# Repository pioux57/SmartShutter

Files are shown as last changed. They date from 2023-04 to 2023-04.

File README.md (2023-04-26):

# SmartShutter Description
>FR Flag Pour la version française, [c'est par ici](READMEfr.md).
## What's this ?
SmartShutter is a DIY project allowing to drive a reflex digital camera, here it is a Nikon D600 but could be any device allowing a binary (on/off) input for shutter and focus, using a "standalone" device but also using a computer.
This project has been done from an original idea of Florent Pin on [storm chasers forum](https://forum.chasseurs-orages.com/viewtopic.php?t=6243), I have took this idea and adapted it to my needs in order to make a more evolved tool.

It provide different features like:
* Lightning detection (3 detection modes)
* Timelapse
* Simply remote control

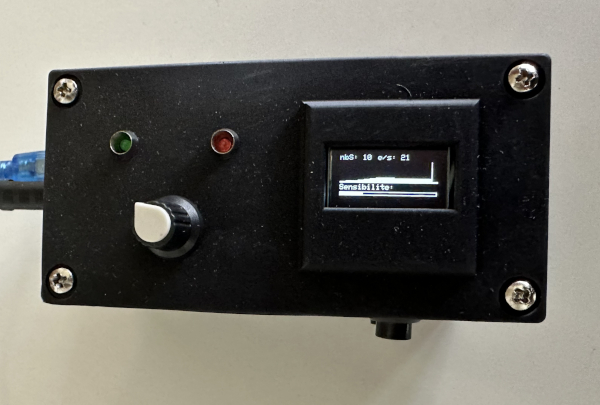
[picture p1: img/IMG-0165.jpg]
Front panel
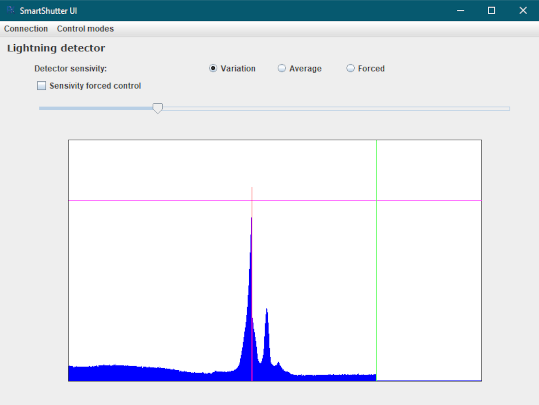
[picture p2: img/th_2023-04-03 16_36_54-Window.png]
UI
 
## And for which purpose ?
I designed it mainly to use my reflex camera to take pictures from stars, galaxys, planets, with my telescope. And additionaly to try to do some lightning pictures. Ability to trigger a picture without touching the telescope setup (no vibrations) and without quiting my computer, is convenient when we do astrophotography.

## User guide
### Main features
There are 3 main features available:
* __Lightning detection__: Triggers a shot from the camera when detect any flash in the direction of the photosensor. 3 detections modes are available:
  * _Variation_ : Will detect a quick change of the ambiant brightness, you can adjust the sensivity of the detection with the potentiometer (depicted by an horizontal line on the screen)
  * _Average_ : Will detect when the brightness exceed the average of the latest measures, you can adjust the sensivity of the detection with the potentiometer (depicted by an horizontal line on the screen)
  * _Forced_ : Will detect when the brightness exceed the threshold set with the potentiometer (depicted by an horizontal line on the screen)
* __Timelapse__: Will trigger a shot from the camera each times the elapsed time is reached. This delay is displayed on the screen in minutes and can be changed using the potentiometer
* __Direct shot__: Will trigger a shot every time you push the "SET" button

### Change feature
If you want to change the selected feature, push the "MODE" button. It will cycle the features like this: `Lightning detection > Timelapse > Direct Shot`.

Lightning detection Timelapse Direct Shot

### Change detection mode
This option is available only in __Lightning detection__, to change the detection mode, push the "SET" button. It will cycle the detection modes like this: `Variation > Average > Forced`.

Lightning detection Lightning detection Lightning detection
>`nbS` means "Number of Shots" - `e/s` means number of measure per second

### Power supply
User any of the standard way to power an Arduino. Through USB using a computer or a portable power bank, or by the Jack power input using a battery case or a live transformer.

# Software

## Arduino code

### The program itself
Code for programming the Arduino controller can be found under `src` folder. It is written in "real" C++ (I'm using PlatformIO under VSCode), but can be easily ported to Arduino IDE.
The program will require following libraries:
```
#include <Wire.h>
#include <Adafruit_GFX.h>
#include <Adafruit_SSD1306.h>
```
>Note that the big hexadecimal part at the beginning was to display my logo on the OLED screen at startup but I've disabled this part to save memory in the microcontroler.

This code can be adapted and transformed but be careful ! I am very close to overload the Arduino available memory, so if you add too much additional variable you may encounter some memory troubleshooting like glitches on the screen, freezing of the Arduino and so on.

### Settings adaptations
You will see at the begining of the code the following constants, they are there in order to adjust some values according to your wiring and components. I give you below the english translation of the comments who indicate what each constant talks about:
```
#define POTENTIOMETER_MAX   940         // Maximum analog value of the potentiometer (you have to measure that by testing it)
#define POTENTIOMETER_MIN   30          // Minimum analog value of the potentiometer (you have to measure that by testing it because it's never a real zero)
#define SENSIBILITY_MAX     100         // Maximum sensitivity wanted
#define SENSIBILITY_MIN     3           // Minimum sensitivity wanted
#define HISTORY_DEPTH       16          // Length of the stored measure array (default 16) !! Careful here, if you put a big value, you will be in memory trouble
#define VALUE_MAX           960         // Maximum analog value of the phototransistor (you have to measure that by testing it)
#define DEBOUNCE_TIME       10          // Button push debounce time
#define TIMELAPSE_GAP       10          // Default timelapse steps duration
#define TIMELAPSE_MAX       1440        // Maximum duration of the whole timelapse cycle
#define USB_LATENCY         10          // Millisecond delay to be used during serial communication with the computer and the UI
```

## Computer UI code
Code for the computer UI is written in groovy and can be executed using a local jdk or jre engine (java). Usually everyone have this installed in a standard Windows OS. The needed jar libraries are provided under `UI/lib` but you can use the latest ones by uncommenting and adapting the maven part in the UI launcher `SmartShutter.bat`.

The program can take 2 optional parameters in input (both can be used at the same time):
* `SmartShutter debug` : Will start the UI in DEBUG MODE
* `SmartShutter lang:en` : Will set the language to english (en) or french (fr). French is default.
>You can update the `.bat` launcher to force any of these parameters to avoid to type it every time.

1. At startup, the software will try to detect the device by itself so it will be better that the device is already connected to the computer before launching the software.
2. Go to "Connection" menu and choose "Connection to SmartShutter", the result of the autodetection will be displayed

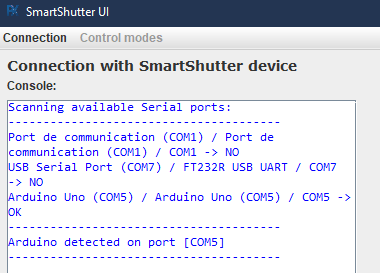
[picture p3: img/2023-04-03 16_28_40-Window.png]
   

3. Click on "Connection" to start the communication between the software and the device

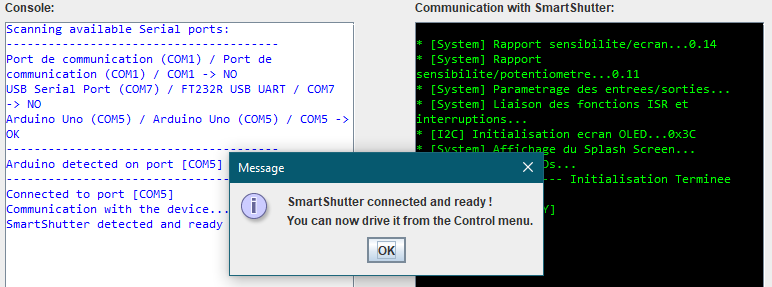
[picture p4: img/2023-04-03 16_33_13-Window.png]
   

Once this step done, you can use all the other features of the software to take control of the device from the computer.
# Hardware

## Skills
This project can be done without any specific skills other than tin soldering. 3D printing skills are optional as you can use the box you want to put the hardware in, or very limited skills as the 3D design is already done for you and available in this repository (stl files). Same for wiring as all the schematics are available in this repository too (fritzing sketch, png and diy files).

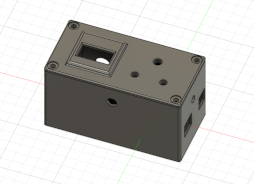
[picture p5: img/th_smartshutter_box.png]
3D Design in Fusion360
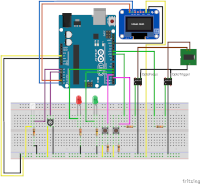
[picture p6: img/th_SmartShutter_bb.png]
Wiring in Fritzing
 

## Material
* 1x Arduino Uno
* 1x [OLED Screen I2C 128x64](https://amzn.eu/d/16eJRzV)
* 1x Red 3mm LED
* 1x Green 3mm LED
* 2x Optocoupler (4N35)
* 1x Potentiometer (0 to 10kOhms)
* 2x Push buttons
* 1x [Phototransistor (3DU5C)](https://amzn.eu/d/ha9QPGW)
* 1x Female Jack 2.5mm connector
* 2x 220 Ohms resistors
* 5x 10k Ohms resistors
* 1x [Prototyping card for soldering additional components](https://amzn.eu/d/ezlYbJF)

## Wiring
I provide 3 types of schematics for wiring to help you building this project.
### Fritzing sketch
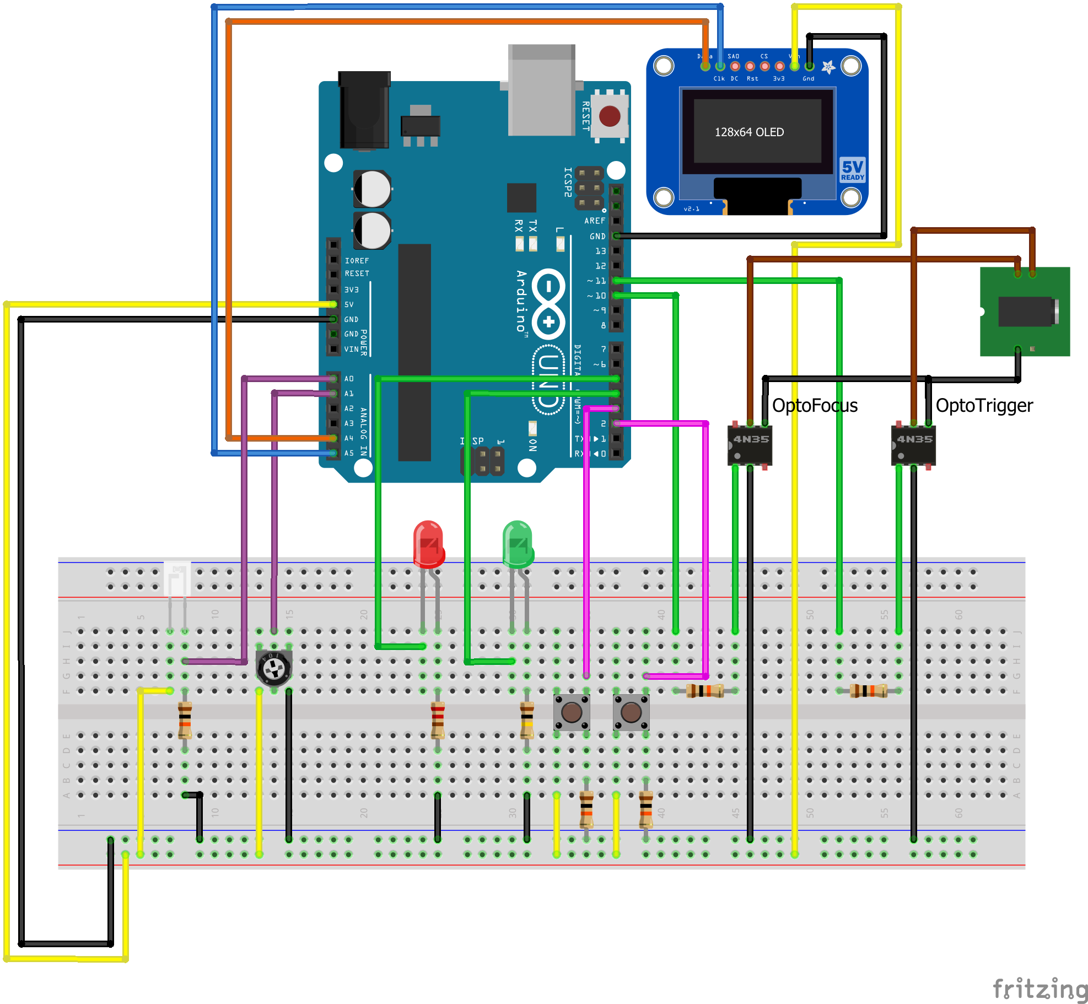
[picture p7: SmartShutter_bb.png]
fzz file

### DIYLC sketch for prototyping card
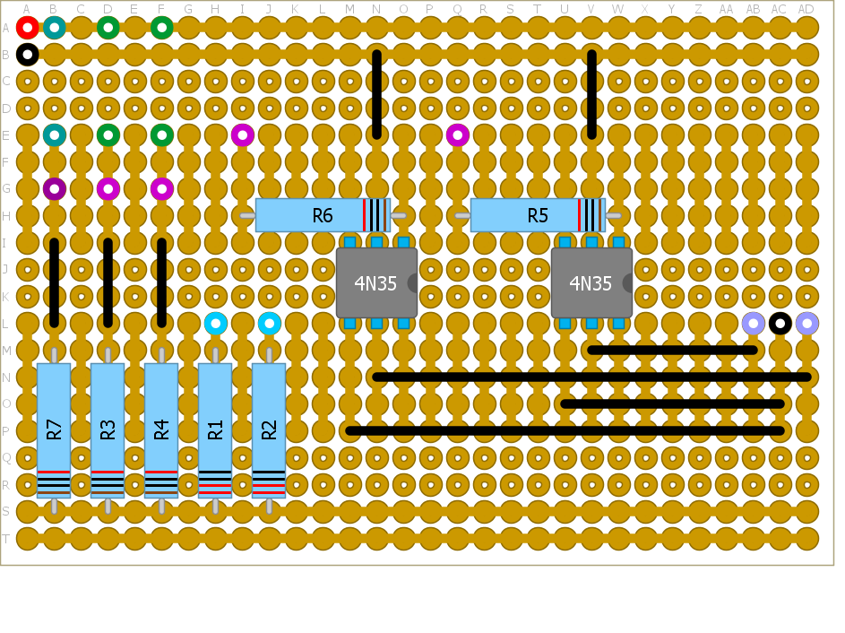
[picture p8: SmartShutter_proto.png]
DIY file

### Electric schematics in png from EasyEDA
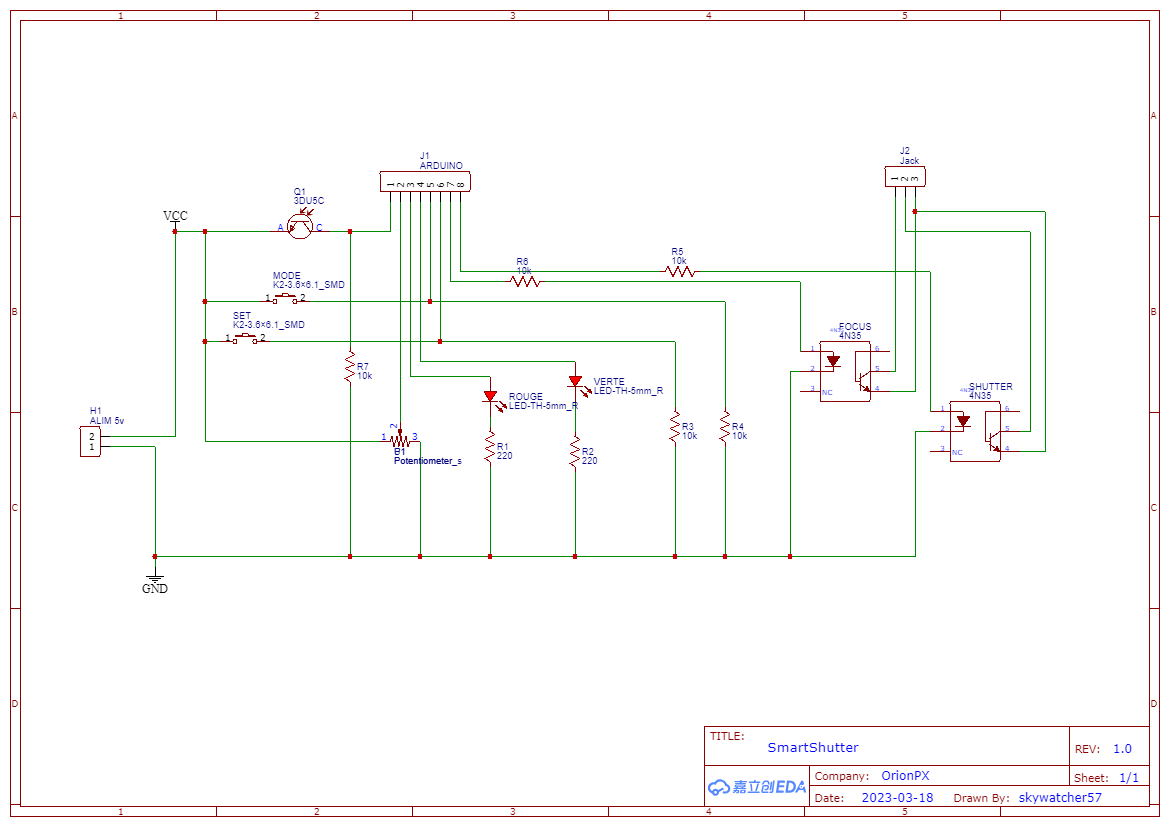
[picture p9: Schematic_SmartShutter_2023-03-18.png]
PNG


### Pictures
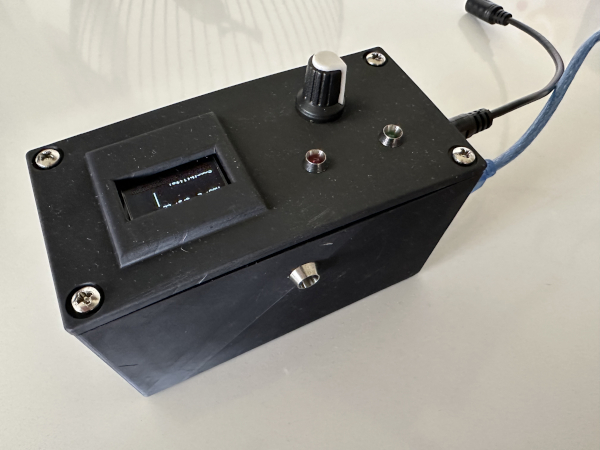
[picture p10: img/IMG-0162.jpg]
Side
Front panel 

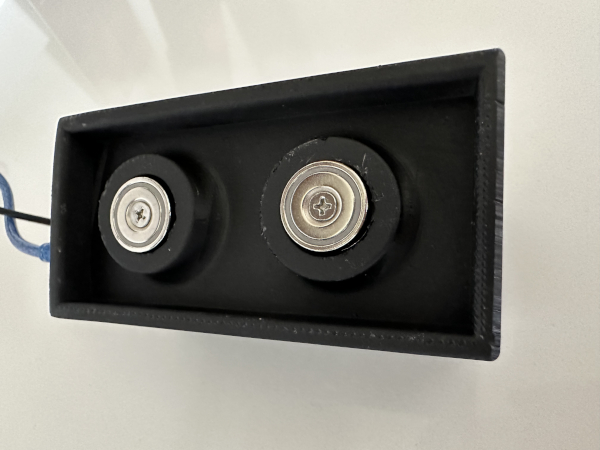
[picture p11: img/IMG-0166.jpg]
Bottom
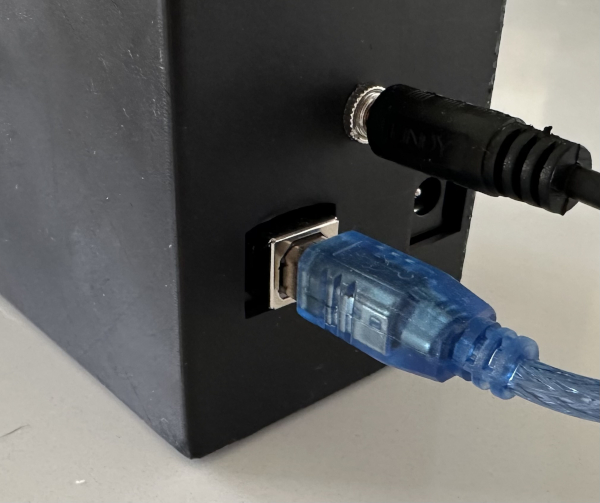
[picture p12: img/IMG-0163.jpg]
Plug panel
 

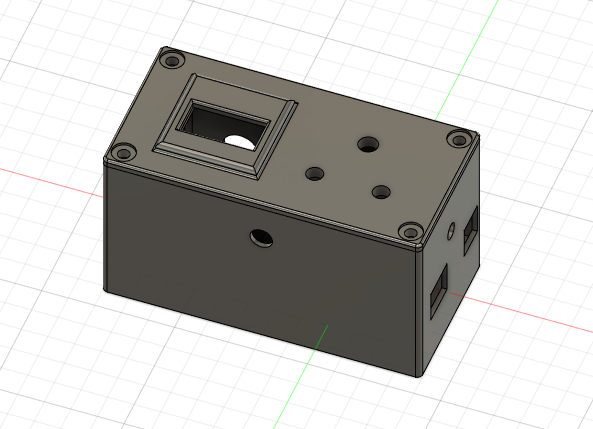
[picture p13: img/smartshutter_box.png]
Fusion screenshot
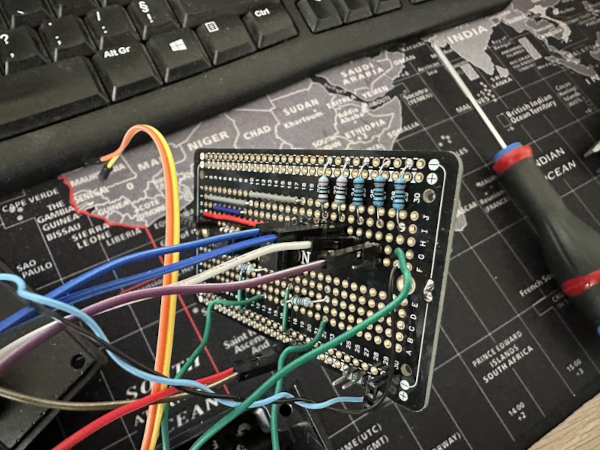
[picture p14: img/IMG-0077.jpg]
Prototyping wiring


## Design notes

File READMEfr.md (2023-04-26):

# SmartShutter Description
## De quoi s'agit-il ?
SmartShutter est un projet DIY qui permet de controler un APN reflex, ici un Nikon D600 mais n'importe quel autre appareil permettant un controle on/off sur l'obturateur et la mise au point peut faire l'affaire, en utilisant un appareil independant mais aussi un ordinateur.
Ce projet a été réalisé à partir d'une idée originale de Florent Pin sur le [forum des chasseurs d'orage](https://forum.chasseurs-orages.com/viewtopic.php?t=6243), je l'ai reprise et adaptée à mes besoin pour en faire un outil plus pointu.

Il fournit 3 fonctionnalités:
* Détéction d'éclair (3 modes de detection)
* Timelapse
* Controle à distance simple

Front panel UI
## A quoi ça sert ?
Je l'ai designé principalement pour utiliser mon APN reflex en astrophoto avec mon telescope. Et en plus, permettre de faire des photos d'éclairs orageux. En astrophoto permettre le déclenchement de l'obturateur sans toucher à l'installation évite les vibrations, ce qui est meilleur pour la qualité des photos.

## Guide utilisateur
### Principales fonctionnalités
3 sont disponibles:
* __Détéction d'éclairs__: Déclenche une prise de vue lorsqu'il détécte un flash dans la direction du capteur photosensible. 3 modes de detection sont disponibles:
  * _Variation_ : Détecte une brusque variation de la lumière ambiante, la sensibilité est réglable avec le potentiometre (représentée par une ligne horizontale sur l'écran)
  * _Moyenne_ : Détecte lorsque la luminosité dépasse la moyenne des dernières mesures, la sensibilité est réglable avec le potentiometre (représentée par une ligne horizontale sur l'écran)
  * _Fixe_ : Détecte lorsque la luminosité dépasse le seuil défini par le potentiometre (représentée par une ligne horizontale sur l'écran)
* __Timelapse__: Déclenche une prise de vue chaque fois que le temps écoulé atteint la valeur réglée. Le délais est affiché en minutes sur l'écran et peut être modifié avec le potentiometre
* __Prise de vue directe__: Déclenche une prise de vue à chaque fois que vous appuyez sur le bouton "SET"

### Changer de fonctionnalité
Pour changer la fonctionnalité active presser le bouton "MODE". Les fonctionnalités vont défiler selon ce sycle: `Détection d'éclair > Timelapse > Prise de vue`.

Lightning detection Timelapse Direct Shot

### Changer le mode de détection
Cette option n'est disponible qu'en __Détection d'éclair__, pour changer de mode de detection, appuyer sur le bouton "SET". Les modes de détection vont défiler selon ce cycle: `Variation > Moyenne > Fixe`.

Lightning detection Lightning detection Lightning detection
>`nbS` signifie "Nombre de prises de vue" - `e/s` signifie "Nombre d'échantillonnages par seconde"

### Alimentation
Utiliser n'importe quel alimentation standard d'Arduino. Avec un cable USB depuis un ordinateur ou une power bank, ou avec une prise Jack en utilisant un support de batterie ou un transfo sur le secteur.

# Logiciel

## Code Arduino

### Le programme
Le programme du microcontroleur se trouve dans le répertoire `src`. Il est écrit en "vrai" C++ (J'utilise PlatformIO depuis VSCode), mais peut facilement être adapté pour l'IDE Arduino.
Le programme nécessite les bibliothéques suivantes:
```
#include <Wire.h>
#include <Adafruit_GFX.h>
#include <Adafruit_SSD1306.h>
```
>Notez que la grosse partie en hexa au début du programme était prévue pour l'affichage de mon logo au démarrage sur l'écran OLED, mais j'ai désactivé cette partie pour économiser de la mémoire sur le microcontroleur.

Ce code peut être adapté et transformé mais faites attention ! Je suis très proche des limites mémoires de l'Arduino, donc si vous ajoutez trop de variable vous risquez de rencontrer des problèmes mémoire comme des glitches d'affichage ou des plantage de l'Arduino.

### Adaptation des réglages
You will see at the begining of the code the following constants, they are there in order to adjust some values according to your wiring and components. I give you below the english translation of the comments who indicate what each constant talks about:
```
#define POTENTIOMETER_MAX   940         // Valeur maximum du potentiometre
#define POTENTIOMETER_MIN   30          // Valeur minimum du potentiometre
#define SENSIBILITY_MAX     100         // Sensibilité maximum réglable
#define SENSIBILITY_MIN     3           // Sensibilité minimum réglable
#define HISTORY_DEPTH       16          // Profondeur de la matrice d'historique des valeurs (default 16)
#define VALUE_MAX           960         // Valeur maximum donnée par le phototransistor
#define DEBOUNCE_TIME       10          // Nb de millisecondes pour debouncer les boutons
#define TIMELAPSE_GAP       10          // Nb de minutes par défaut du timelapse
#define TIMELAPSE_MAX       1440        // Durée maximum du timelapse en minutes
#define USB_LATENCY         10          // Latence de la communication serie
```

## Code du logiciel PC
Le code de l'interface utilisateur est écrit en groovy et peut être executé avec un jdk ou jre local (java). Habituellement tout le monde en a une version sur un OS standard Windows. Les bibliothéques Java nécessaires sont fournies dans le répertoire `UI/lib` mais vous pouvez utiliser les dernières version en décommentant et en adaptant la partie Maven dans le lanceur `SmartShutter.bat`.

Le programme peut prendre 2 paramètres facultatifs (ils peuvent être utilisés en même temps):
* `SmartShutter debug` : Lance l'écran en mode DEBUG
* `SmartShutter lang:en` : Force la langue en anglais (en) ou français (fr). Le français est la langue par défaut.
>Vous pouvez modifier le lanceur `.bat` pour forcer la langue ou le mode et éviter de devoir le passer en paramètre à chaque fois.

1. Au démarrage, le logiciel va essayer de détecter le périphérique automatiquement, il est donc préferable d'avoir déjà connecté le SmartShutter à l'ordinateur avant de lancer le logiciel.
2. Aller dans le menu "Communication" et choisir "Communication avec le SmartShutter, le résultat de l'autodétection y sera affiché.

   

3. Cliquer sur "Connexion" pour démarrer la communication entre le SmartShutter et le logiciel.

   

Une fois cette étape effectuée, vous pouvez utiliser les autres fonctionnalités du logiciel et prendre le controle de l'appareil depuis l'ordinateur.
# Hardware

## Compétences
Ce projet peut être réalisé sans compétences particulières autres que la soudure à l'étain. Les compétences en impression 3D sont facultatives car vous pouvez utiliser n'importe quel boitier pour y placer l'éléctronique, ou toutefois des compétences limitées en impression 3D étant donné que le design du boitier est déjà fait et disponible dans ce repository (fichiers stl). Idem pour le cablage, tous les schémas sont disponibles dans ce repository également (fichiers fritzing, png et diy).

3D Design in Fusion360 Wiring in Fritzing

## Materiel
* 1x Arduino Uno
* 1x [Ecran OLED I2C 128x64](https://amzn.eu/d/16eJRzV)
* 1x LED Rouge Red 3mm
* 1x LED Verte 3mm
* 2x Optocoupleur (4N35)
* 1x Potentiometre (0 to 10kOhms)
* 2x Boutons poussoir
* 1x [Phototransistor (3DU5C)](https://amzn.eu/d/ha9QPGW)
* 1x Connecteur Jack femelle 2.5mm
* 2x Résistances 220 Ohms
* 5x Résistances 10k Ohms
* 1x [Carte de Prototypage pour la soudure des composants additionnels](https://amzn.eu/d/ezlYbJF)

## Cablage
Je fournis 3 types de schémas pour le cablage pour vous aider à réaliser ce projet.
### Sketch Fritzing
fzz file
### Sketch DIYLC pour la carte de prototypage
DIY file
### Schéma éléctrique normalisé en png depuis EasyEDA
PNG

### Photos
Front panel Side

Bottom Plug panel

Fusion screenshot Prototyping wiring

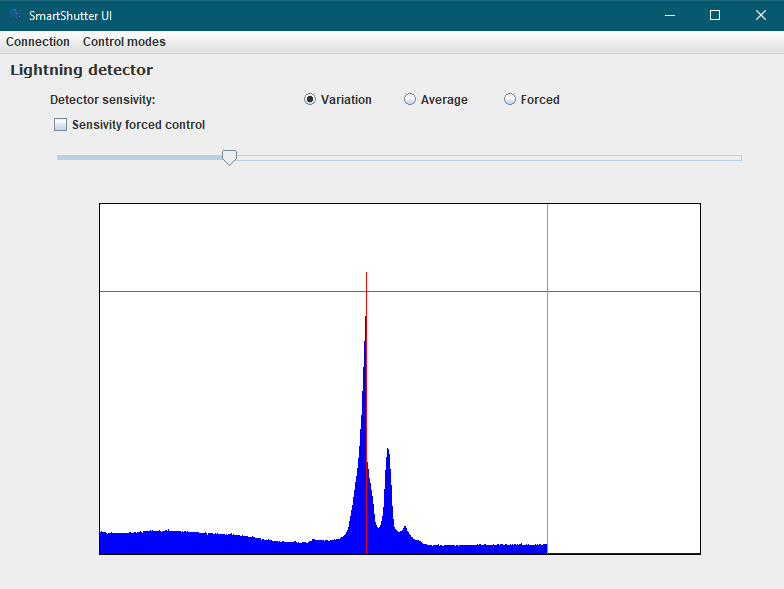
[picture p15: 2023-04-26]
img/2023-04-03 16_36_54-Window.png

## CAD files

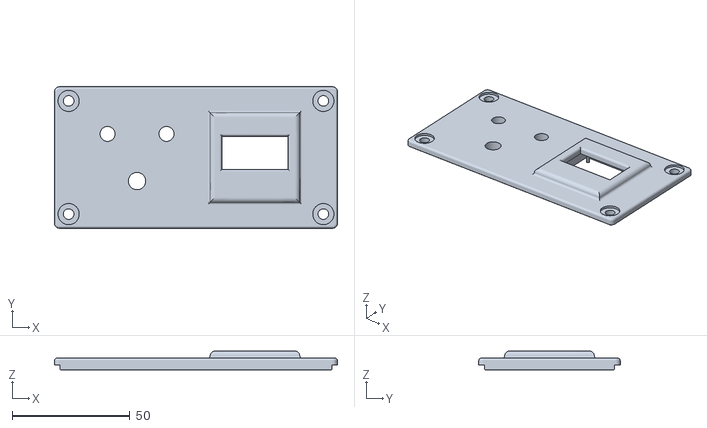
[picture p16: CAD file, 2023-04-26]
SmartShutter v11_couv.stl
120.0 x 60.0 x 8.00

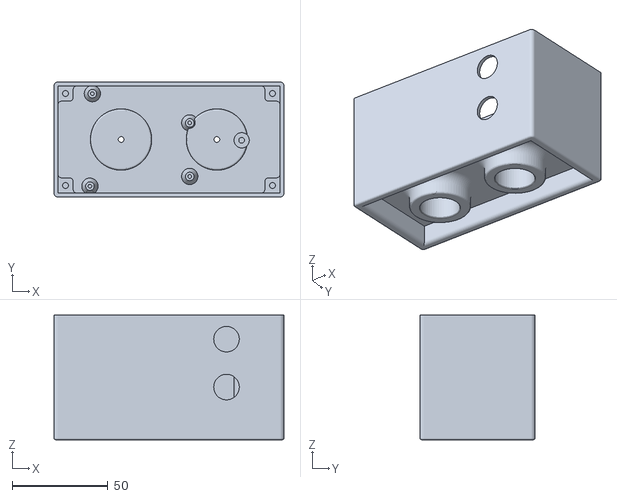
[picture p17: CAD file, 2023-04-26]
SmartShutter v12_base.stl
120.0 x 60.0 x 65.0

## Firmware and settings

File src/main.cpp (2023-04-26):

/*
 *  Boitier de commande pour le pilotage d'un appareil reflex et commande de focus sur telescope.
 *  Mode de detection de variation brusque de lumière via un phototransistor de type 3DU5C pour déclenchement automatique de la prise de vue en cas de détection de foudre
 *  Fonction de declenchement programmé pour fonction timelapse
 *  Composants: 
 *    - Affichage sur écran OLED via protocole I2C
 *
 *  Dev: Christian Poupounot // Date: 14 mars 2023
 *  Adapte du code de Florent Pin (https://forum.chasseurs-orages.com/viewtopic.php?t=6243) credits orginaux ;)
 *  Codage bitmap 24bits via http://javl.github.io/image2cpp/
 */

/********************************************/
//           Inclusion Bibliothéques
/********************************************/
#include <Arduino.h>
#include <Wire.h>
#include <Adafruit_GFX.h>
#include <Adafruit_SSD1306.h>

/********************************************/
//              Hardware
/********************************************/
// Ecran OLED
#define OLED_RESET 4
Adafruit_SSD1306 display(128,64, &Wire, OLED_RESET);

/********************************************/
//              Software
/********************************************/
// Versionning
#define SOFTWARE_VERSION 	"1.11"
#define SOFTWARE_AUTHOR		"Christian Poupounot"

// // 'logo-orionpx', 128x64px
// const unsigned char logo_orionpx [] PROGMEM = {
// 	0x00, 0x00, 0x00, 0x00, 0x00, 0x00, 0x00, 0x00, 0x00, 0x00, 0x00, 0x00, 0x00, 0x00, 0x00, 0x00, 
// 	0x00, 0x00, 0x00, 0x00, 0x00, 0x00, 0x00, 0x00, 0x00, 0x00, 0x00, 0x00, 0x00, 0x00, 0x00, 0x00, 
// 	0x00, 0x00, 0x00, 0x00, 0xff, 0xff, 0xfd, 0xff, 0x80, 0x00, 0x0f, 0xff, 0x80, 0x00, 0x00, 0x00, 
// 	0x00, 0x00, 0x00, 0x00, 0xff, 0xff, 0xfe, 0xff, 0x00, 0x00, 0x1f, 0xff, 0x00, 0x00, 0x00, 0x00, 
// 	0x00, 0x00, 0x00, 0x00, 0xff, 0xff, 0xff, 0x7e, 0xc0, 0x00, 0x1f, 0xff, 0x00, 0x00, 0x00, 0x00, 
// 	0x00, 0x00, 0x00, 0x00, 0xff, 0xff, 0xff, 0xbd, 0xc0, 0x00, 0x3f, 0xfe, 0x00, 0x00, 0x00, 0x00, 
// 	0x00, 0x00, 0x00, 0x00, 0xff, 0xff, 0xff, 0xc3, 0xe0, 0x00, 0x3f, 0xfe, 0x00, 0x00, 0x00, 0x00, 
// 	0x00, 0x00, 0x00, 0x00, 0xff, 0xff, 0xff, 0xc3, 0xe0, 0x00, 0x7f, 0xfc, 0x00, 0x00, 0x00, 0x00, 
// 	0x00, 0x00, 0x00, 0x00, 0xff, 0xff, 0xff, 0xc7, 0xf0, 0x00, 0x7f, 0xfc, 0x00, 0x00, 0x00, 0x00, 
// 	0x00, 0x00, 0x00, 0x00, 0xff, 0xff, 0xff, 0xd3, 0xf0, 0x00, 0xdf, 0xf8, 0x00, 0x00, 0x00, 0x00, 
// 	0x00, 0x00, 0x00, 0x00, 0xff, 0xff, 0xff, 0xb1, 0xf8, 0x00, 0xdf, 0xf0, 0x00, 0x00, 0x00, 0x00, 
// 	0x00, 0x00, 0x00, 0x00, 0xff, 0xff, 0xff, 0xfb, 0xf8, 0x01, 0xdf, 0xf0, 0x00, 0x00, 0x00, 0x00, 
// 	0x00, 0x00, 0x00, 0x00, 0xff, 0xff, 0xff, 0xfb, 0xfc, 0x01, 0xff, 0xe0, 0x00, 0x00, 0x00, 0x00, 
// 	0x00, 0x00, 0x00, 0x00, 0xff, 0xf0, 0x03, 0xfd, 0xfc, 0x03, 0xbf, 0xe0, 0x00, 0x00, 0x00, 0x00, 
// 	0x00, 0x00, 0x00, 0x00, 0xff, 0xe0, 0x00, 0xfd, 0xfe, 0x03, 0xbf, 0xc0, 0x00, 0x00, 0x00, 0x00, 
// 	0x00, 0x00, 0x00, 0x00, 0xff, 0xe0, 0x00, 0x7d, 0xfe, 0x07, 0xbf, 0xc0, 0x00, 0x00, 0x00, 0x00, 
// 	0x00, 0x00, 0x00, 0x00, 0xff, 0xe0, 0x00, 0x7e, 0xff, 0x07, 0x7f, 0x80, 0x00, 0x00, 0x00, 0x00, 
// 	0x00, 0x00, 0x00, 0x00, 0xff, 0xe0, 0x00, 0x7e, 0xff, 0x0f, 0x7f, 0x80, 0x00, 0x00, 0x00, 0x00, 
// 	0x00, 0x00, 0x00, 0x00, 0xff, 0xe0, 0x00, 0x3f, 0x7f, 0x8f, 0xff, 0x00, 0x00, 0x00, 0x00, 0x00, 
// 	0x00, 0x00, 0x00, 0x00, 0xff, 0xf0, 0x00, 0x3f, 0x7f, 0x9f, 0xfe, 0x00, 0x00, 0x00, 0x00, 0x00, 
// 	0x00, 0x00, 0x00, 0x00, 0xff, 0xf0, 0x00, 0x3f, 0xff, 0xdf, 0xfe, 0x00, 0x00, 0x00, 0x00, 0x00, 
// 	0x00, 0x00, 0x00, 0x00, 0xff, 0xe0, 0x00, 0x3f, 0xff, 0xfe, 0xfc, 0x00, 0x00, 0x00, 0x00, 0x00, 
// 	0x00, 0x00, 0x00, 0x00, 0xff, 0xf0, 0x00, 0x3f, 0xbf, 0xff, 0xfc, 0x00, 0x00, 0x00, 0x00, 0x00, 
// 	0x00, 0x00, 0x00, 0x00, 0xff, 0xf0, 0x00, 0x7f, 0xff, 0xfd, 0xf8, 0x00, 0x00, 0x00, 0x00, 0x00, 
// 	0x00, 0x00, 0x00, 0x00, 0xff, 0xf0, 0x00, 0x7f, 0xdf, 0xfd, 0xf8, 0x00, 0x00, 0x00, 0x00, 0x00, 
// 	0x00, 0x00, 0x00, 0x00, 0xff, 0xf0, 0x00, 0xff, 0xdf, 0xfd, 0xf0, 0x00, 0x00, 0x00, 0x00, 0x00, 
// 	0x00, 0x00, 0x00, 0x00, 0xff, 0xf0, 0x01, 0xff, 0xef, 0xfb, 0xf0, 0x00, 0x00, 0x00, 0x00, 0x00, 
// 	0x00, 0x00, 0x00, 0x00, 0xff, 0xf0, 0x07, 0xff, 0xef, 0xfb, 0xe0, 0x00, 0x00, 0x00, 0x00, 0x00, 
// 	0x00, 0x00, 0x00, 0x00, 0xff, 0xff, 0xff, 0xff, 0xef, 0xfb, 0xc0, 0x00, 0x00, 0x00, 0x00, 0x00, 
// 	0x00, 0x00, 0x00, 0x00, 0xff, 0xff, 0xff, 0xff, 0xf7, 0xfb, 0xc0, 0x00, 0x00, 0x00, 0x00, 0x00, 
// 	0x00, 0x00, 0x00, 0x00, 0xff, 0xff, 0xff, 0xff, 0xf7, 0xfb, 0x80, 0x00, 0x00, 0x00, 0x00, 0x00, 
// 	0x00, 0x00, 0x00, 0x00, 0xff, 0xff, 0xff, 0xff, 0xfb, 0x9d, 0x80, 0x00, 0x00, 0x00, 0x00, 0x00, 
// 	0x00, 0x00, 0x00, 0x00, 0xff, 0xff, 0xff, 0xff, 0xfb, 0xfd, 0xc0, 0x00, 0x00, 0x00, 0x00, 0x00, 
// 	0x00, 0x00, 0x00, 0x00, 0xff, 0xff, 0xff, 0xff, 0xf9, 0xfe, 0xc0, 0x00, 0x00, 0x00, 0x00, 0x00, 
// 	0x00, 0x00, 0x00, 0x00, 0xff, 0xff, 0xff, 0xff, 0xb9, 0xfe, 0xe0, 0x00, 0x00, 0x00, 0x00, 0x00, 
// 	0x00, 0x00, 0x00, 0x00, 0xff, 0xff, 0xff, 0xfe, 0x7b, 0xff, 0xe0, 0x00, 0x00, 0x00, 0x00, 0x00, 
// 	0x00, 0x00, 0x00, 0x00, 0xff, 0xff, 0xff, 0xfc, 0x7b, 0xff, 0x70, 0x00, 0x00, 0x00, 0x00, 0x00, 
// 	0x00, 0x00, 0x00, 0x00, 0xff, 0xff, 0xff, 0xe0, 0xfb, 0xff, 0xf0, 0x00, 0x00, 0x00, 0x00, 0x00, 
// 	0x00, 0x00, 0x00, 0x00, 0xff, 0xf0, 0x00, 0x00, 0xff, 0xff, 0xf8, 0x00, 0x00, 0x00, 0x00, 0x00, 
// 	0x00, 0x00, 0x00, 0x00, 0xff, 0xf0, 0x00, 0x01, 0xf7, 0xff, 0xfc, 0x00, 0x00, 0x00, 0x00, 0x00, 
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
// };

////////////////////////////////////////
// Constantes de réglage
#define POTENTIOMETER_MAX   940         // Valeur maximum du potentiometre
#define POTENTIOMETER_MIN   30          // Valeur minimum du potentiometre
#define SENSIBILITY_MAX     100         // Sensibilité maximum réglable
#define SENSIBILITY_MIN     3           // Sensibilité minimum réglable
#define HISTORY_DEPTH       16          // Profondeur de la matrice d'historique des valeurs (default 16)
#define VALUE_MAX           960         // Valeur maximum donnée par le phototransistor
#define DEBOUNCE_TIME       10          // Nb de millisecondes pour debouncer les boutons
#define TIMELAPSE_GAP       10          // Nb de minutes par défaut du timelapse
#define TIMELAPSE_MAX       1440        // Durée maximum du timelapse en minutes
#define USB_LATENCY         10

////////////////////////////////////////
// Communication
struct UARTByte {
	bool value_ok = false;
	int  value = 0;
};

////////////////////////////////////////
// Config I/O
const int triggerPIN        = 11;       // Commande de l'optocoupleur pour le déclenchement
const int prefocusPIN       = 12;       // Commande de l'optocoupleur pour le focus
const int transistorPIN     = A0;       // Entrée analogique du phototransistor
const int potoPIN           = A1;       // Entrée analogique du potentiometre
/*
 *   A4 - Ecran OLED
 *   A5 - Ecran OLED
 */
const int greenLedPIN       = 5;        // Pin Led verte
const int redLedPIN         = 4;        // Pin Led rouge
const int buttonModePIN     = 2;        // Bouton Mode (PULL-DOWN)
const int buttonSetPIN      = 3;        // Bouton Set (PULL-DOWN)

////////////////////////////////////////
// Variables globales
byte shutterMode                = 0;        // 0=Mode orage     / 1=mode timelapse  / 2=remote
byte detectionMode              = 0;        // 0=Mode variation / 1=mode moyenne    / 2=mode fixe
bool displaySplash			    = true;
bool initFinished               = false;
int potentiometerValue          = 0;
byte potentiometerValueForced   = 0;
int sensibility                 = 0;
float ratioScreen               = 0.0;
byte i;
// Variable PC
bool usbDriven                  = false;    // Controle via USB
bool usbDisconnect              = false;    // Indique une deconnexion du PC
bool sendData2Serial            = false;
bool lockSensibility            = false;
// Variables mode orage
float ratioSensibility          = 0.0;
bool samplingPhase              = true;     // Mode initial d'échantillonnage avant de lancer la détection
float ratioGraph                = 0.0;
float thresholdValue            = 0.0;
int sensorValue                 = 0;        // Dernière valeur lue
int prevSensorValue             = 0;        // Précédente valeur lue
int gap                         = 0;
int averageValue                = 0;
int nbShot                      = 0;
int sampleRate                  = 0;
int sampleNb                    = 0;
unsigned long int lastRate      = 0;
int valueHistory[HISTORY_DEPTH];
byte indexHistory               = 0;
byte indexGraph                 = 0;
byte graphMaxPlot               = 28;
byte plotWidth                  = 1;
byte yThreshold                 = 0;
byte barHeight                  = 0;
// Variables mode timelapse
float ratioTimelapse            = 0.0;
int timelapseGap                = TIMELAPSE_GAP;
bool timelapseWIP               = false;
unsigned long int lastShot      = 0;

////////////////////////////////////////
// Variables hors registres pour les interruptions
volatile boolean buttonModeWIP  = false;
volatile boolean buttonSetWIP   = false;

/********************************************/
//              Déclaration fonctions
/********************************************/
void displayOLEDSplash();
void triggerShot();
bool readModeButton();
bool readSetButton();

void modeLightning();
void modeTimelapse();
void modeRemote();
void modeUSB();
void usbControl(bool state);

void modeButtonISR();       // Interrupt Service Routine on button Mode
void setButtonISR();        // Interrupt Service Routine on button Set

/********************************************/
//              Initialisation
/********************************************/
void setup() {
	// Ouverture communication avec le PC pour debug
    Serial.begin(9600);
    Serial.println("");

    // Calcul ratios
    ratioScreen         = (float)128/POTENTIOMETER_MAX;
    ratioSensibility    = (float)SENSIBILITY_MAX/POTENTIOMETER_MAX;
    ratioTimelapse      = (float)TIMELAPSE_MAX/POTENTIOMETER_MAX;
    ratioGraph          = (float)graphMaxPlot/VALUE_MAX;
    plotWidth           = 128/HISTORY_DEPTH;
    Serial.print(F("* [System] Rapport sensibilite/ecran..."));
    Serial.println(ratioScreen);
    Serial.print(F("* [System] Rapport sensibilite/potentiometre..."));
    Serial.println(ratioSensibility);

    // Initialisation de la matrice de mesure
    for ( i = 0 ; i < HISTORY_DEPTH ; i++ ){ valueHistory[i] = 0; }

    // Hardware init
    Serial.println(F("* [System] Parametrage des entrees/sorties..."));
    pinMode(triggerPIN,OUTPUT);
    pinMode(prefocusPIN,OUTPUT);
    pinMode(redLedPIN,OUTPUT);
    pinMode(greenLedPIN,OUTPUT);
    pinMode(buttonModePIN,INPUT);
    pinMode(buttonSetPIN,INPUT);

    digitalWrite(triggerPIN,LOW);
    digitalWrite(prefocusPIN,HIGH);    // Activation permanente du focus
    digitalWrite(redLedPIN,LOW);
    digitalWrite(greenLedPIN,LOW);

    // Interruptions
    Serial.println(F("* [System] Liaison des fonctions ISR et interruptions..."));
    attachInterrupt(digitalPinToInterrupt(buttonModePIN), modeButtonISR , RISING);
    attachInterrupt(digitalPinToInterrupt(buttonSetPIN) , setButtonISR  , RISING);

    // Initialisation Ecran OLED
	Serial.println(F("* [I2C] Initialisation ecran OLED...0x3C"));
	display.begin(SSD1306_SWITCHCAPVCC, 0x3C);  // Initialise avec l'adresse I2C 0x3D (Pour le 128x64) 
	
    // Affichage du splash screen pour connaitre la version du software installé
    Serial.println(F("* [System] Affichage du Splash Screen..."));
    displayOLEDSplash();
	display.setTextColor(WHITE);

    // Test des leds
    Serial.println(F("* [System] Test LEDs..."));
    digitalWrite(redLedPIN,HIGH);
    delay(1000);
    digitalWrite(redLedPIN,LOW);
    digitalWrite(greenLedPIN,HIGH);
    delay(1000);
    digitalWrite(greenLedPIN,LOW);

    initFinished = true;
    Serial.println(F("* [System] ---------- Initialisation Terminee ------------"));
    delay(200);
    Serial.print(F("[SMARTSHUTTER READY]"));
    delay(500);
    Serial.println("");
}

/********************************************/
//              Main Block
/********************************************/
void loop() {
    display.clearDisplay();

    // Relevé des valeurs
    sensorValue = analogRead(transistorPIN);
    sampleNb++;
    if (!lockSensibility) { potentiometerValue = POTENTIOMETER_MAX - analogRead(potoPIN); } // On soustrait car on veut une lecture inversée de la position du potar
    else{ potentiometerValue = potentiometerValueForced * 10; }

    if (usbDriven && sendData2Serial){
        Serial.print(F("pvalue="));
        Serial.println(potentiometerValue);
        delay(USB_LATENCY);
        Serial.print(F("value="));
        Serial.println(sensorValue);
        delay(USB_LATENCY);
    }

    if (readModeButton() || usbDisconnect){
        if (!usbDisconnect){
            shutterMode++;
            if (shutterMode >= 3){shutterMode = 0;}
        }

        usbDisconnect = false;

        display.setTextSize(2);
        display.setTextColor(WHITE);
        display.setCursor(0,0); // 9 pixels pour un char (8) + son espace (1)

        switch(shutterMode){
            case 0:
                display.println("Mode");
                display.println(" Orage");
                
                samplingPhase   = true;
                indexHistory    = 0;
                nbShot          = 0;
            break;
            case 1:
                display.println("Mode");
                display.println(" TimeLapse");
                timelapseWIP = false;
            break;
            case 2:
                display.println("Mode");
                display.println(" Controle");
            break;
        }

        display.setTextSize(1);
        display.display();
        delay(1000);
        display.clearDisplay();
    }

    // if (!usbDriven){
        switch(shutterMode){
            case 0:
                modeLightning();
            break;
            case 1:
                modeTimelapse();
            break;
            case 2:
                modeRemote();
            break;
        }
    // } else {
    //     modeUSB();
    // }
    
    display.display();

}

/********************************************/
//              Fonctions
/********************************************/

//--------------------------------------------
// Gestion du mode orage
void modeLightning(){
    
    // Gestion du mode de detection
    if (readSetButton()){
        detectionMode++;
        if (detectionMode >= 3){detectionMode = 0;}
    }

    // Taille du graph en fonction du mode
    if (samplingPhase){graphMaxPlot = 40;;}
    else{
        switch(detectionMode){
            case 0: graphMaxPlot = 28; break;
            case 1: graphMaxPlot = 28; break;
            case 2: graphMaxPlot = 40; break;
        }
    }

    // Calcul du taux de mesures
    if (millis() - lastRate > 1000){
        sampleRate = sampleNb;
        sampleNb = 0;
        lastRate = millis();
    }

    // Decalage axe x du curseur du graph
    indexGraph++;
    if (indexGraph >= HISTORY_DEPTH) {indexGraph = 0;}

    display.fillRect(indexGraph*plotWidth,10,1,graphMaxPlot,WHITE);

    // Historique des mesures
    valueHistory[indexHistory] = sensorValue;
    indexHistory++;
    if (indexHistory >= HISTORY_DEPTH) {
        indexHistory = 0;
        samplingPhase = false; // On a un tableau complet, on peut passer au mode détection
    }

    // Affichage du graph et Calcul moyenne des mesures
    for (i = 0 ; i < HISTORY_DEPTH ; i++){
        averageValue += valueHistory[i];
        barHeight = (int)valueHistory[i]*ratioGraph;
        // display.fillRect(i*2,10,2,barHeight,WHITE);
        display.fillRect(i*plotWidth,(graphMaxPlot+10)-barHeight,plotWidth,barHeight,WHITE);
    }
    averageValue = averageValue / HISTORY_DEPTH;

    // Calcul seuil de detection
    sensibility = SENSIBILITY_MAX - (potentiometerValue * ratioSensibility);

    // Saturation du phototransistor
    if(sensorValue > VALUE_MAX) {digitalWrite(redLedPIN,1);} else {digitalWrite(redLedPIN,0);}  

    // Detection d'un dépassement de seuil
    if (!samplingPhase){
        switch(detectionMode){
            // Mode variation
            case 0:
                gap = sensorValue - prevSensorValue;
                if(gap > sensibility){triggerShot();}
            break;
            // Mode moyenne
            case 1:
                // Affichage du seuil de déclenchement sur le graph
                yThreshold = (graphMaxPlot+10)-((averageValue + sensibility)*ratioGraph);
                display.drawFastHLine(0,yThreshold,128,WHITE);

                // Detection du dépassement
                if(sensorValue >= (averageValue + sensibility)){triggerShot();}
            break;
            // Mode fixe
            case 2:
                // Affichage du seuil de déclenchement sur le graph
                thresholdValue = (float)sensibility / 100;
                thresholdValue *= VALUE_MAX;
                yThreshold = (graphMaxPlot + 10)-((int)thresholdValue*ratioGraph);
                display.drawFastHLine(0,yThreshold,128,WHITE);

                // Detection du dépassement
                if(sensorValue >= (int)thresholdValue){triggerShot();}
            break;
        }
    }

    ////////////////////// MODE ECHANTILLONAGE //////////////////////
    if (samplingPhase){
        // Affichage valeur courante
        display.setCursor(0,0); // 9 pixels pour un char (8) + son espace (1)
        display.print("Valeur capteur:");
        display.println(sensorValue);
        display.setCursor(0,52); // 9 pixels pour un char (8) + son espace (1)
        display.println("Echantillonnage...");
    }
    ////////////////////// MODE DETECTION //////////////////////
    else {
        // Affichage du nombre de déclenchements
        display.setCursor(0,0); // 9 pixels pour un char (8) + son espace (1)
        display.print("nbS: ");
        display.println(nbShot);
        display.setCursor(50,0); // 9 pixels pour un char (8) + son espace (1)
        display.print("e/s: ");
        display.println(sampleRate);

        // Affichage bargraph sensibilité
        if (detectionMode == 0 || detectionMode == 1){
            display.setCursor(0,40); // 9 pixels pour un char (8) + son espace (1)
            display.println("Sensibilite:");
            display.drawRect(0, 50, 127, 5, WHITE);
            int bar_size = (potentiometerValue * ratioScreen);
            display.fillRect(0, 50, bar_size, 5, WHITE);
        }

        if (detectionMode ==1){
            // Affichage sensibilité moyenne
            display.setCursor(0,56); // 9 pixels pour un char (8) + son espace (1)
            display.print("Valeur moyenne: ");
            display.println(averageValue);
        }
    }
    prevSensorValue = sensorValue;
}

//--------------------------------------------
// Gestion du mode TimeLapse
void modeTimelapse(){
    // Demarrage / Arret du timelapse
    if (usbDriven){
        display.setTextSize(2);
        display.setCursor(0,25);
        display.println(F("Controle  Via USB"));
        display.setTextSize(1);
    }
    else {
        if (readSetButton()){
            timelapseWIP = !timelapseWIP;
            lastShot = 0;
        }

        if (timelapseWIP){
            int secElapsed = (millis() - lastShot) / 1000;  // Nombre de secondes écoulées depuis la derniere PDV
            if (secElapsed >= timelapseGap * 60){
                triggerShot();
                lastShot = millis();
            }
            display.setTextSize(1);
            display.setCursor(0,0);
            display.print(F("Decompte: "));
            display.setTextSize(2);
            display.setCursor(30,15);
            
            display.print( timelapseGap * 60 - secElapsed );
            display.print("s");
            
            display.setTextSize(1);
            display.setCursor(0,50);
            display.print(F("Interval: "));
            display.print(timelapseGap * 60);
            display.println("s");
        } else {
            // Calcul réglage du timelapse
            timelapseGap = potentiometerValue * ratioTimelapse;
            if (timelapseGap < 0){timelapseGap = 0;}
            if (timelapseGap > TIMELAPSE_MAX){timelapseGap = TIMELAPSE_MAX;}

            display.setTextSize(2);
            display.setCursor(50,10);
            display.println(timelapseGap);
            display.setTextSize(1);
            display.setCursor(40,50);
            display.println(" (minutes)");
        }
    }
}

//--------------------------------------------
// Gestion du mode Remote
void modeRemote(){
    if (readSetButton()){ triggerShot(); }

    display.setCursor(0,28);
    display.println(F(" Attente..."));
}

//--------------------------------------------
// Gestion du mode Remote
void modeUSB(){
    display.setCursor(0,28);
    display.println(F(" Controle via PC"));
}

//--------------------------------------------
// Affichage du Splash screen sur l'écran OLED
void displayOLEDSplash(){
    // display.clearDisplay();
    // display.drawBitmap(0, 0,  logo_orionpx, 128, 64, WHITE);
    // display.display();
    // delay(2000);
    display.clearDisplay();
	display.setTextSize(2);
	display.setTextColor(WHITE);
	display.setCursor(0,0); // 9 pixels pour un char (8) + son espace (1)
	display.println("Smart");
    display.println("  Shutter");
	display.setTextSize(1);
    display.println("");
    display.print("Firmware: v");
	display.println(SOFTWARE_VERSION);
	display.setTextSize(1);
	display.print(SOFTWARE_AUTHOR);

	display.display();
	displaySplash = false;
    delay(3000);
    display.clearDisplay();
}
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
